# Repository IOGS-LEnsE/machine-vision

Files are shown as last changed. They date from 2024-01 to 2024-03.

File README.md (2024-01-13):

# Machine Vision Platform
Documentation of the pedagogic platform about Machine Vision used during labwors @ LEnsE / IOGS / France

Watch the complete documentation [here !!!](https://iogs-lense.github.io/machine-vision/)

## About Institut d'Optique and LEnsE
The **LEnsE**, ***Laboratoire d'Enseignement Expérimental***, [Website](http://lense.institutoptique.fr/)

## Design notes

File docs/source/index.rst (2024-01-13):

.. Machine-Vision platform documentation master file, created by
   sphinx-quickstart on Sat Jan 13.
   You can adapt this file completely to your liking, but it should at least contain the root `toctree` directive.

Documentation of Machine Vision platform
========================================

.. caution::
   This documentation website is still in development

**Machine Vision** GitHub repository contains documentations of the pedagogic technical platform developed for Machine Vision labworks and projects of students.

The GitHub repository of this project : `Machine Vision <https://github.com/IOGS-LEnsE/machine-vision>`_

|

.. toctree::
   :maxdepth: 1
   :caption: Machine Vision
   
	Machine Vision platform<contents/machine_vision>

.. toctree::
   :maxdepth: 1
   :caption: Materials

	Overview<contents/material_overview>
	Electronic board<contents/material_board>
	Testing procedure<contents/material_testing>

.. toctree::
   :maxdepth: 1
   :caption: How To

.. toctree::
   :maxdepth: 1
   :caption: Contributors
   
	Main contributors<contents/main_contributors>
	Students contributions<contents/other_contributors>

About the LEnsE
---------------

The **Experimental Teaching Laboratory** (*LEnsE*, for *Laboratoire d’ENSeignement Expérimental*) is a major structure of the *Institut d'Optique* engineering school. It offers remarkably strong training that contributes 25% of the total curriculum. It is an impressive structure where students have access to a large diversity of material and human resources to be able to gain the skills to become excellent experimenters recognized in their field.

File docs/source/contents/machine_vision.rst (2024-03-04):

Machine Vision Platform
=======================

Machine vision
--------------

**Machine vision** encompasses all industrial and non-industrial applications in which a **combination of hardware and software** provide operational guidance to devices in the execution of their functions based on the capture and processing of images.

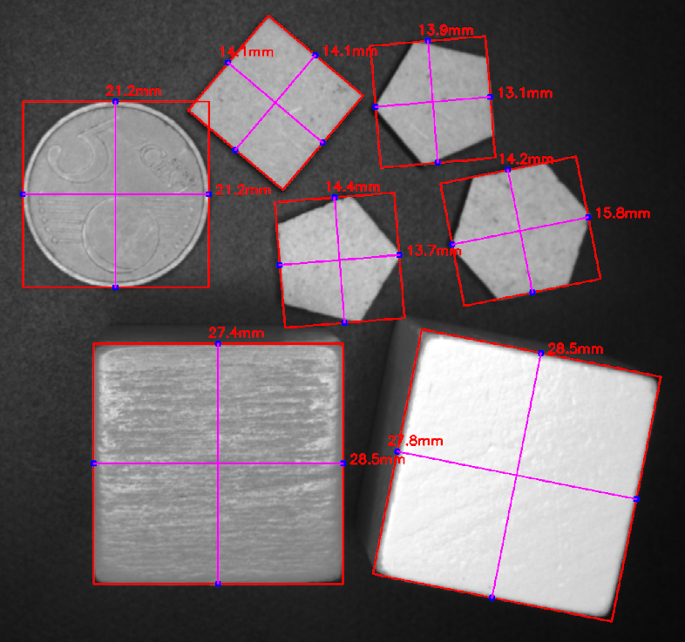
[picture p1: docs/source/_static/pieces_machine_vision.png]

  
  2022 LEnsE.

For example, machine vision is used to inspect parts in a production chain without stopping the manufacturing flow. If defaults are detected on a part (wrong color, bad shape...), a sorting system can eject bad elements.

|

In manufacturing settings, machine vision systems required the following items:

#. **Lighting** to illuminate the scene to make the object features visible.
#. **Lens** to captures the image and delivers it to a sensor.
#. **Image sensor** to collect a digital image of the object.
#. **Computer** (or digital signal processor) to process the images and extract the required information.

|

You can find more information about machine vision, for example, on the Cognex website : https://www.cognex.com/en-au/what-is/machine-vision

Pedagogical platform
--------------------

The platform was developped in order to sort pieces 

It is based on :

#. *EffiLux* **Effi-Ring** industrial lights 
#. A `Dobot Magician **Conveyor** <https://www.dobot.nu/en/product/dobot-conveyor-belt-kit/>`_ (step-motor and conveyor belt)
#. A *Basler* camera sensor

Pedagogical objectives
----------------------

Niveau 1 : pilotage du convoyeur
Niveau 2 : détection de forme et de couleur par caméra

Dans le milieu industriel, le convoyage de pièces, la détection de certains défauts ou le tri par types d’objets sont très couramment utilisés. L’objectif de ce projet est de mettre en place un système de tri de pièces à l’aide d’un convoyeur et d’un système de traitement d’images.

La mise en mouvement du convoyeur se fait par l’intermédiaire d’un moteur pas à pas. Le tri des pièces (par couleur ou forme) utilise une caméra associée à une Raspberry Pi permettant de faire le traitement des images et de transmettre le résultat à un système de tri.

Main steps
----------

Interface de base
~~~~~~~~~~~~~~~~~

Des bibliothèques de base en Python sont disponibles pour le développement autour des caméras Basler. Ces exemples nécessitent opencv et les API pypylon (Basler). Ces exemples peuvent être inclus dans des interfaces graphiques en PyQt6.

`Exemples pour cameras IDS et Basler <https://github.com/IOGS-Digital-Methods/SupOpNumTools/tree/main/src/SupOpNumTools/camera>`_

Des exemples (très complets) sont disponibles dans les projets suivants :  `IHM PyQt6 pour cameras IDS et Basler <https://github.com/IOGS-LEnsE/labwork-GUI>`_

Une première version d’une interface de commande (obsolète) des caméras IDS USB2 est disponible.  `IHM PyQt5 pour camera IDS - obsolete <https://github.com/IOGS-LEnsE-embedded/Python_SupOpLibraries/tree/main/CameraControl/IDS/LEnsE_version1>`_

*Cette application nécessite PyQt5, OpenCV, l’API PyUeye et les drivers des caméras.*

Partie matérielle
~~~~~~~~~~~~~~~~~

* Comprendre le fonctionnement d'un moteur pas à pas (indépendamment de ceux de la table) - `Vidéo <https://www.youtube.com/watch?v=eyqwLiowZiU>`_
* Etudier les signaux à appliquer sur le moteur pas à pas pour l'entrainer en rotation
* Etudier le driver `**TMCSILENTSTEPSTICK** <https://fr.farnell.com/trinamic/tmc-silentstepstick/carte-driver-moteur-pas-a-pas/dp/2822153>`_ (basé  sur un composant de type **TMC2100**) et l'associer au moteur pas à pas
* Voir aussi les tutoriels associés aux cartes Nucléo parlant des étages de puissance
	* Régler l’intensité lumineuse d’une LED – partie puissance
	* Faire varier la vitesse d’un moteur à courant continu – partie pont en H
* Réaliser un programme de pilotage simple pour entrainer en rotation le moteur

Partie logicielle / traitement d’image
~~~~~~~~~~~~~~~~~~~~~~~~~~~~~~~~~~~~~~

* Prendre en main PyQt6 sous Python 3
* Tester les fonctionnalités de base de Open CV sous Python

Autres étapes

* Mettre en place une communication RS232 entre la Raspberry Pi (via un programme en Python) et une carte Nucléo
* Décider des données à transmettre de l’un à l’autre et d’un protocole à mettre en oeuvre
* Tester le code de la carte Nucléo à l’aide de commande directement saisie dans un terminal
* Voir aussi les tutoriels associés aux cartes Nucléo parlant des communications inter-systèmes
	* Echanger des données entre deux systèmes communicants (et les tutoriels précédents sur la communication RS232)

Une série de tutoriels sont en cours de rédaction à ce sujet :  `Tutoriel Python / PySerial et PyQt5/6 pour échange entre un PC et une Nucléo <http://lense.institutoptique.fr/mine/python-interfacage-et-affichage/>`_

Ils sont basés sur les exemples suivants :  `IHM PyQt5 pour échange entre un PC et une Nucléo <https://github.com/IOGS-LEnsE-embedded/Python_SupOpLibraries/tree/main/SerialComm>`_

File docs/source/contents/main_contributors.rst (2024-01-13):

Labworks Platforms Development / Main Contributors
==================================================

Initial Idea
------------

The original idea of this platform borned with a regular request for training in Machine Vision to the *Continuing Education* service of the **Institut d'Optique**.

This platform was also designed as a main industrial application of image processing for our future engineer in photonics.

Initial Design
--------------

The initial design of the platform was performed by **Thierry AVIGNON**, technical engineer at LEnsE, and **Julien VILLEMEJANE**, professor at LEnsE.

The main objective was to integrate the **basic components of an industrial machine vision platform** (image sensor, lighting system, image processing) and a sorting application level.

Learning outcomes targeted by this platform are for our future engineer :

* list the main components of a machine vision system
* choose and interface image sensor (and optical system) to obtain relevant images
* experiment the impact of the lighting system on the quality of the image
* develop a sorting application of pieces, depending on their shape or/and their color

Main development
----------------

A first platform was developped at LEnsE as part of a three weeks students project in 2022 by Victoire de SALEON, Flora SILBERZAN, Oscar BOUCHER, Martin COLLIGNON, Samuel GERENTE and Hugo LASSIETTE (promo 2024), framed by **Thierry AVIGNON** and **Julien VILLEMEJANE**. A poster of their work is available by following `this link <http://lense.institutoptique.fr/ressources/MINE/Realisations/PIMS/2022_VisionIndustrielle/2022_PIMS_VisionIndustrielle_Poster.pdf>`_.

Continuous Upgrades
-------------------

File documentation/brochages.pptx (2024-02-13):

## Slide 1

Computer Vision / L476 board

Control of computer vision bench / Dobot conveyor

Functions

- Step Motor Control (x2)
  - Step Motor Driver – TMC2100
- RF data transmission
  - RN41/42 – Evaluation Board XV
- Position sensor SEN0239 (x3)
- Light control (x3 – R / G / B)

PROJECT VERSION

Based on Nucleo L476RG board

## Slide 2

Computer Vision / L476 board

Control of computer vision bench / Dobot conveyor

TX

PC_10

PC_12

Morpho Gauche / Nucléo

PC_11

PD_2

E5V

GPIO2_STATUS

RX

POUSS. 3

PC_9

PB_8

PB_9

Morpho Droit / Nucléo

PC_8

PC_6

PC_5

POUSS. 2

POUSS. 1

PA_13

GND

nRF24 / SCK

AVDD

GND

PA_5 / SCK

U5V

PA_12

PA_14

PA_15

5V

3.3V

nRF24 / MOSI

nRF24 / MISO

PA_6 / MISO

PA_7 / MOSI

D10 / CS

PA_11

PB_12

PB_11

LED 1

LED 2

RESET_N

GND

PB_7

PC_13

Vin

PA_0

GND

GND

nRF24 / CSN

nRF24 / CE

nRF24 / IRQ

PC_7

PA_9

PA_8

GND

PB_1

PB_2

MOT1_CFG3

CAPT 1

CAPT 2

PC_14

PC_15

MOT2_EN

MOT2_DIR

MOT2_STEP

PB_10

PB_4

PB_5

PB_13

PB_15

PB_14

MOT1_CFG2

MOT1_CFG1

MOT1_EN

Not Used

Digital Output

Digital Input

Analog Input

CAPT 3

ECLAIR 3

PH_0

PH_1

PC_2

A2

PA_1

PB_0

V_OUT_REF

MOT1_STEP

MOT1_DIR

D1

PA_10

PB_3

PC_4

AGND

MOT1_STEP*

ECLAIR 2

ECLAIR 1

Analog Output

PC_3

PC_0

PC_1

D0

* Must be set as input

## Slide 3

TMC2100 – Step Motor Driver

Step Motor Driver / Motor 1 / TMC2100

MBED6 Library : https://github.com/IOGS-LEnsE-embedded/MBED6_SupOpLibraries/tree/main/TMC2100

Nucleo Board

Not Used

Digital Output

Digital Input

Analog Input

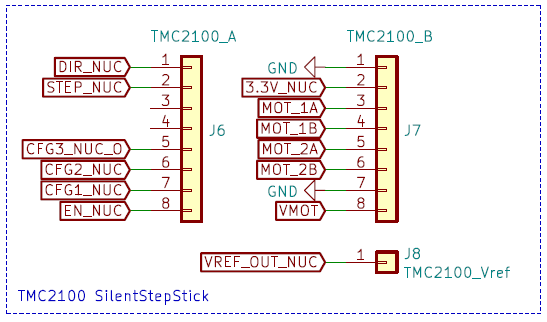
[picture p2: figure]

GND

TMC2100 / Motor1

PA_10

PB_3

MOT1_DIR

MOT1_STEP

3.3V

PB_1

MOT1_CFG3

PB_13

PB_15

PB_14

MOT1_CFG2

MOT1_CFG1

MOT1_EN

PC_4

PWM

MOT1_STEP

A2

V_OUT_REF

Analog Output

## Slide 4

nRF24 – RF transmission

nrF24L01 module for RF data transmission

MBED6 Library : https://github.com/IOGS-LEnsE-embedded/MBED6_SupOpLibraries/tree/main/nRF24

Nucleo Board

Not Used

Digital Output

Digital Input

Analog Input

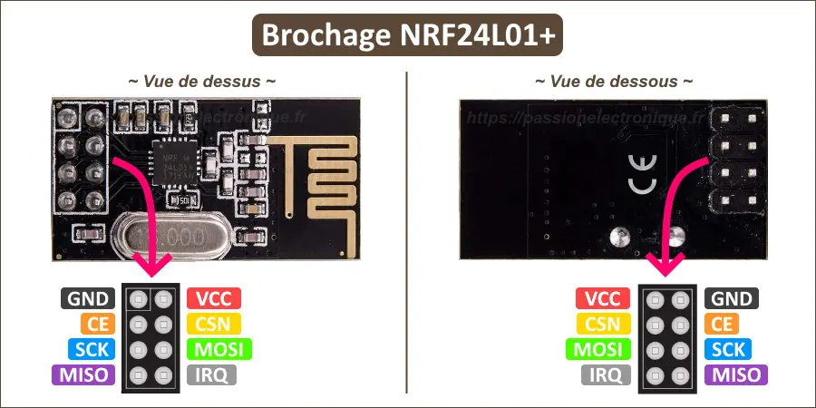
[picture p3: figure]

3.3V

GND

nRF24L01 / RF

PA_9

PA_8

PC_7

IRQ

CE

CSN

PA_6 / MISO

PA_7 / MOSI

PA_5/ SCK

SPI

MISO

MOSI

CLK

Analog Output

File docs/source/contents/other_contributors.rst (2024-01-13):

Light Source Radiant Intensity Measuring Platform
=================================================

.. caution::
   This documentation section is still in development

Machine Learning and first documentation
----------------------------------------

In 2023, during his first year of training, **Alexis CORBILLET** (2025 promotion) worked with five others classmates on the beta version of the machine vision bench. 

They worked on hardware part to develop a sorting system, but also on a software able to interact with users and process images from an IDS sensor to detect the color and the shape of the pieces to sort. Their system was based on Machine Learning algorithm.

The entire documentation of their application was written by Alexis using `Sphinx <https://www.sphinx-doc.org/en/master/>`_ : https://alex6crbt.github.io/Industrial_Vision/

The GitHub repository https://github.com/Alex6Crbt/Industrial_Vision was also developed by Alexis for his own training on GitHub processes. This repository and its documentation served as a basis for setting up this first LEnsE technical repository.

Alexis was helped by **Olivier LEVEQUE**, researcher at ONERA, the French Aerospace Lab.

Students Projects year by year
------------------------------

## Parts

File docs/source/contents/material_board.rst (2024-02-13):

Machine Vision Electronic Control board
=======================================

This platform is associated to an **electronic board** for controlling : the translation of the conveyor, the activation of each sorting system, the activation of the lighting system.

.. note::
	This board can be used to control 2 different step-motors.

Microcontroller
---------------

Pinouts
~~~~~~~

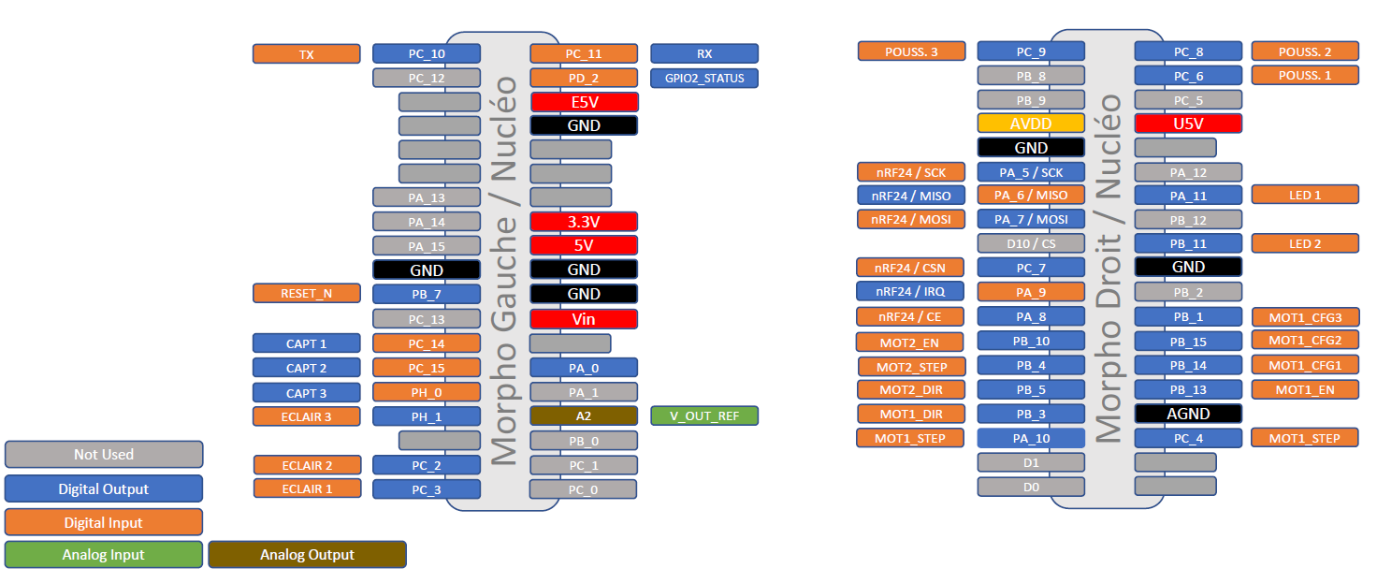
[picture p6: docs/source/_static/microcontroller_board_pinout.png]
Pinout of the microcontroller

   
   Pinouts of the board
   
Step-motor of the conveyor
--------------------------

The step-motor must be powered by a **4.6** to **4.8 V** continuous source, connected to the ... connector of the board.

Power stage and step motor driver
---------------------------------

Two step-motors can be controlled independently  by two **TMC2100** (`Kit TMC Silent Step Stick <https://fr.farnell.com/trinamic/tmc-silentstepstick/carte-driver-moteur-pas-a-pas/dp/2822153>`_) drivers.

The first driver (**Motor 1**) can be configured by CFG1, CFG2 and CFG3 pins (see `TMC2100 Documentation <https://www.utmel.com/productdetail/trinamicmotioncontrolgmbh-tmc2100tat-5369295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>`_).
The second driver (**Motor 2**) is already set up as CFG3=open (*External reference voltage on pin AIN*), CFG2/1=0b01 (*HalfSteps*).

.. list-table:: TMC2100 Pins / Motor 1
   :widths: 34 33 33
   :header-rows: 1

   * - TMC2100
     - Elec Board
     - Nucleo Board
   * - EN (In)
     - MOT1_EN (Out)
     - PB_13
   * - DIR (In)
     - MOT1_DIR (Out)
     - PB_3
   * - STEP (In)
     - MOT1_STEP (Out)
     - PA_10
   * - CFG1 (In)
     - MOT1_CFG1 (Out)
     - PB_14
   * - CFG2 (In)
     - MOT1_CFG2 (Out)
     - PB_15
   * - CFG3 (In)
     - MOT1_CFG3 (Out)
     - PB_1
   * - VREF_AIN (Analog In)
     - V_OUT_REG (Analog Out)
     - PA_4 / A2

To configure CFG3 as open pin, the J2 jumper must be removed (*External reference voltage on pin AIN*). To connect the CFG3 input pin of the TMC2100 driver to the Nucleo Board (MOT1_CFG3 pin), the J2 jumper must be in place.

.. list-table:: TMC2100 Pins / Motor 2
   :widths: 34 33 33
   :header-rows: 1

   * - TMC2100
     - Elec Board
     - Nucleo Board
   * - EN (In)
     - MOT2_EN (Out)
     - PB_10
   * - DIR (In)
     - MOT2_DIR (Out)
     - PB_5
   * - STEP (In)
     - MOT2_STEP (Out)
     - PB_4
   * - VREF_AIN (Analog In)
     - V_OUT_REG (Analog Out)
     - PA_4 / A2

An external power supply must be connected to the J5 connector (VMOT). This nominal supply for the xxx step-motor is 4V, for a maximal current of 1A per phase.

More details on the `TMC2100 Documentation <https://www.utmel.com/productdetail/trinamicmotioncontrolgmbh-tmc2100tat-5369295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>`_.

A library for TMC2100 and an example of use is available : `TMC2100 Library and example <https://github.com/IOGS-LEnsE/machine-vision/blob/main/progs/step_motor_tmc2100/step_motor_tmc2100.zip>`_.

Presence sensors
----------------

Three digital inputs are dedicated to **SEN0239** infrared presence detectors, including supply of the sensors.

.. list-table:: Presence Sensors Pins
   :widths: 34 33 33
   :header-rows: 1

   * - Sensor
     - Elec Board
     - Nucleo Board
   * - Sensor 1
     - CAPT1 (In)
     - PC_14
   * - Sensor 2
     - CAPT2 (In)
     - PC_15
   * - Sensor 3
     - CAPT3 (In)
     - PH_0

Communication
-------------

A **RN41/42 XV** module or a **nrF24L01** module could be implemented for radio-frequency communication. 

BlueTooth communication via RN41/42 module
~~~~~~~~~~~~~~~~~~~~~~~~~~~~~~~~~~~~~~~~~~

RF communication via nRF24L01 module
~~~~~~~~~~~~~~~~~~~~~~~~~~~~~~~~~~~~

.. list-table:: nRF24L01 Pins
   :widths: 34 33 33
   :header-rows: 1

   * - nRF24L01
     - Elec Board
     - Nucleo Board
   * - SCK / In
     - nRF24 / SCK (Out)
     - PA_5 / D13 *
   * - MISO / Out
     - nRF24 / MISO (In)
     - PA_6 / D12
   * - MOSI / In
     - nRF24 / MOSI (Out)
     - PA_7 / D11
   * - CSN / In
     - nrF24 / CSN (Out)
     - PC_7
   * - IRQ / Out
     - nrF24 / IRQ (In)
     - PA_9
   * - CE / In
     - nrF24 / CE (Out)
     - PA_8

* LED1 (LD2 on board led) could not be used if nrF24 is connected

Lighting system
---------------

The lighting system is an EFFI-Ring from the Effilux company, type RGB (ref ??). Red, Blue and Green lights can be controlled independently.

IMAGE OF THE LIGHT

A M12-5pins connector is used to control and power the ring. The power supply is 24V. The pins controlling the 3 independent sources are connected to a MOSFET transistor.

.. list-table:: Light Control Pins
   :widths: 34 33 33
   :header-rows: 1

   * - Light Source
     - Elec Board
     - Nucleo Board
   * - Red
     - ECLAIR 1
     - PC_3
   * - Green
     - ECLAIR 2
     - PC_2
   * - Blue
     - ECLAIR 3
     - PH_1

Lights are activated on a **low-level state** of the previous outputs (output = 0).

An external power supply must be connected to the J19 connector (V_ECLAIRAGE). The nominal supply for the EFFi-Ring source is 24V.

More details on the `EFFI-Ring Documentation <https://www.effilux.com/fr/produits/annulaire/effi-ring>`_.

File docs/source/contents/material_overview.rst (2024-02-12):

Overview of the platform
========================

The **LEnsE** team developped a platform to reproduce a part of an **industrial system of machine vision**.

Machine Vision platform is a combination of a **conveyor** driven in movement by a **step motor**, a sorting system, a **CMOS industrial sensor** and a **lighting system**.

PICTURE OF THE SYSTEM

Materials
---------

Conveyor and sorting system
~~~~~~~~~~~~~~~~~~~~~~~~~~~

This platform is mainly based on a **Dobot conveyor** that permits to transport small pieces 

Step Motor
""""""""""

A **step-motor** is used to move the conveyor. It is driven by a **TMC SILENTSTEPSTICK** from *Analog Devices*.

The step-motor must be powered up by a 4.6 to 4.8 V power supply.

Sensors
"""""""

Three **SEN0239** infrared presence detectors could be implemented on the board.

SCHEMA ?

A digital output is at a **high level** when an object is detected close to the sensor and at a low level when no object is detected. The sensibility (i.e. the detection distance) can be set up by modifying the value of a potentiometer using a screwdriver.

Sorter System
~~~~~~~~~~~~~

The conveyor is equiped with three home-made sorter systems, based on a servomotor.

IMAGE ?

CMOS Sensor
~~~~~~~~~~~

The CMOS Camera is a **Basler** *XXXX*. The **Pylon Camera Software Suite** is a software package comprised of an easy-to-use SDK, drivers, configuration tools and vTools that you can use to operate any Basler camera and utilize image processing using a Windows PC.

IMAGE OF THE SENSOR

You can also interface this camera with a Python program, using the `PyPylon library <https://github.com/basler/pypylon>`_.

An example based on the PyPylon library is given on this GitHub page : https://github.com/IOGS-Digital-Methods/SupOpNumTools/blob/main/src/SupOpNumTools/camera/cameraBasler.py

More details on the `Basler Documentation Website <https://www.baslerweb.fr/fr/20-cameras-matricielles>`_.

| 

Electronic control board
~~~~~~~~~~~~~~~~~~~~~~~~

This platform is associated to an **electronic board** for controlling : the translation of the conveyor, the activation of each sorting system, the activation of the lighting system.

.. note::
	This board can be used to control 2 different step-motors.

IMAGE OF THE BOARD

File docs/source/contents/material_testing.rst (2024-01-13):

Machine Vision Testing procedures
=================================

Power supplies
--------------

Lighting system
---------------

Conveyor system
---------------

Image acquisition
-----------------

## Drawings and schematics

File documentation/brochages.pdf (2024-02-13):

# Computer Vision / L476 board

# Control of computer vision bench / Dobot conveyor

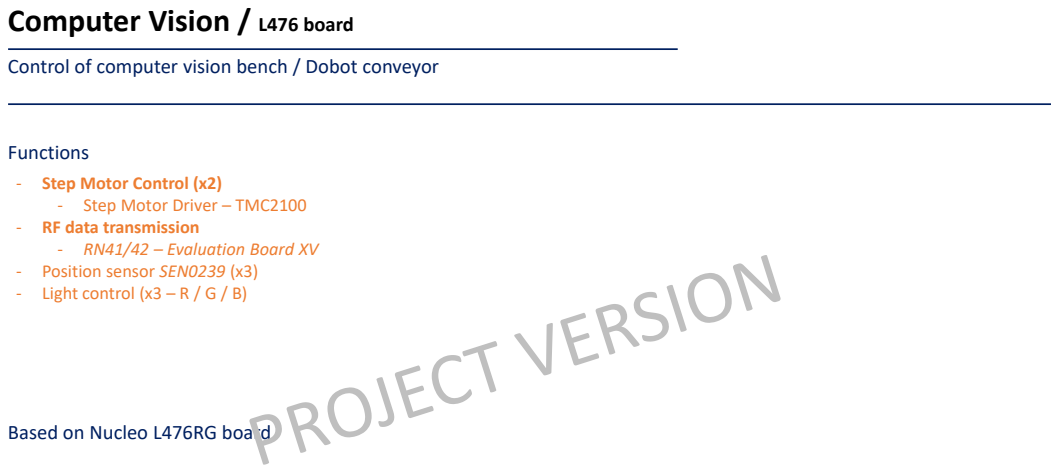
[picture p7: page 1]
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

Based on Nucleo L476RG board

# Computer Vision / L476 board

# Control of computer vision bench / Dobot conveyor

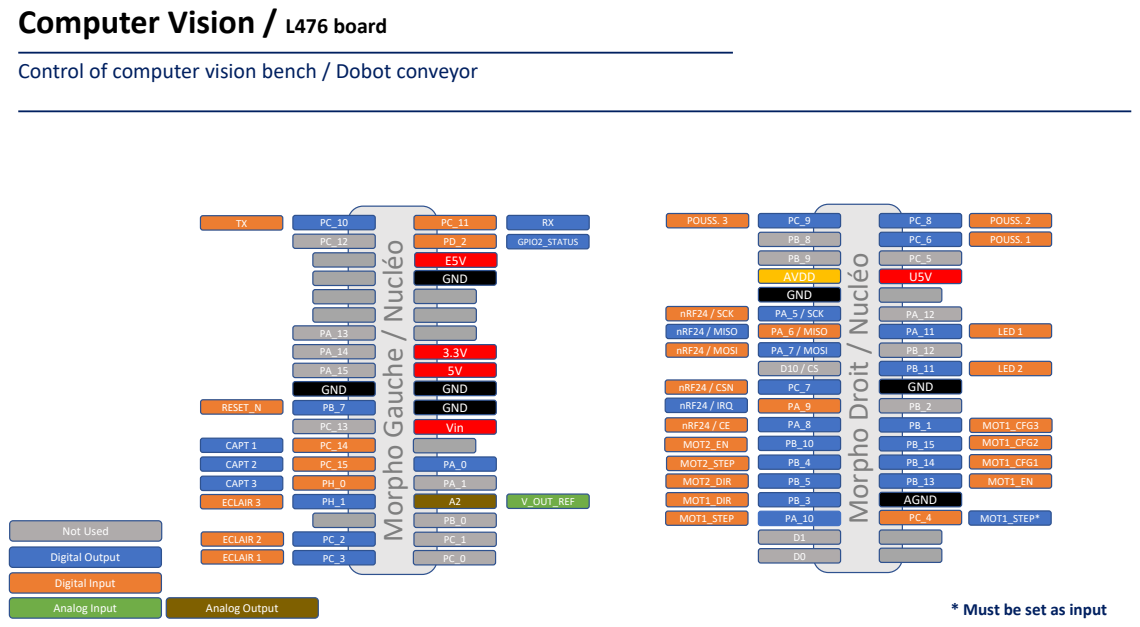
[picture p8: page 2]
Digital Output; Digital Input; Analog Input; PA_6 / MISO; PA_7 / MOSI; PA_5 / SCK; GND; AGND; AVDD; PD_2 E5V GND; GND Vin; RESET_N; GPIO2_STATUS; nRF24 / SCK; nRF24 / MISO; nRF24 / MOSI; nRF24 / IRQ; nRF24 / CSN; nRF24 / CE; Not Used; CAPT 1; CAPT 2; CAPT 3; ECLAIR 3; ECLAIR 2; ECLAIR 1; Analog Output; V_OUT_REF; POUSS. 3; POUSS. 2; POUSS. 1; LED 1; LED 2; MOT1_STEP; MOT1_DIR; MOT1_EN; MOT1_CFG1; MOT1_CFG2; MOT1_CFG3; MOT2_DIR; MOT2_STEP; MOT2_EN; MOT1_STEP*

Morpho Gauche / Nucléo

Morpho Droit / Nucléo

* Must be set as input

# TMC2100 – Step Motor Driver

# Step Motor Driver / Motor 1 / TMC2100 TMC2100 / Motor1

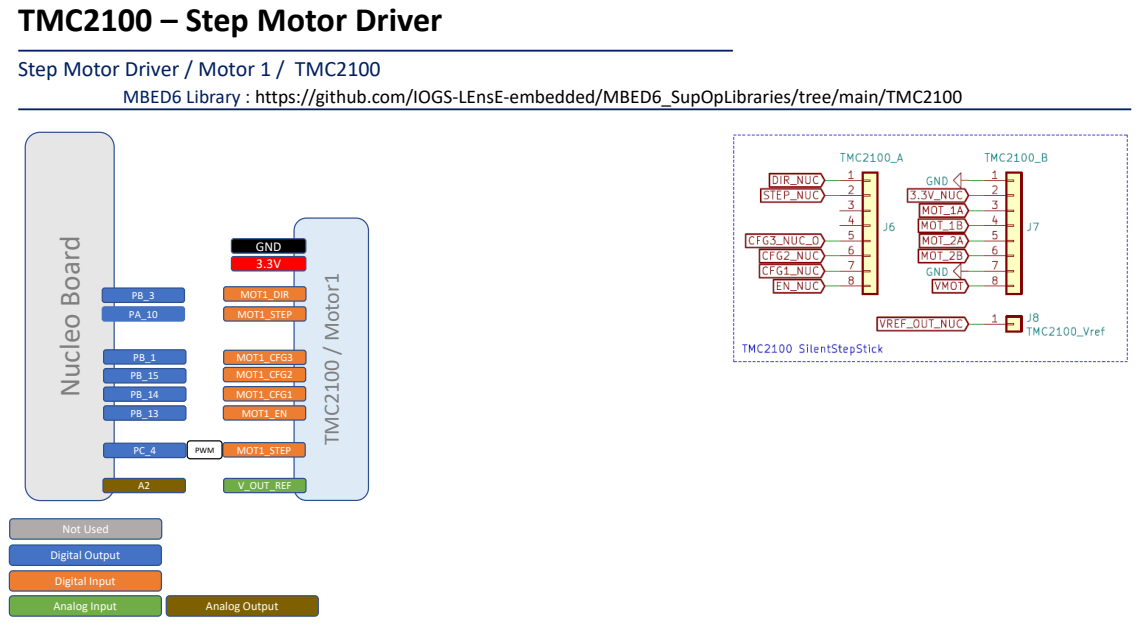
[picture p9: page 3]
Nucleo Board; GND 3.3V; MOT1_STEP; MOT1_DIR; MOT1_EN; MOT1_CFG1; MOT1_CFG2; MOT1_CFG3; PWM; V_OUT_REF; Digital Output; Digital Input; Not Used

MBED6 Library : https://github.com/IOGS-LEnsE-embedded/MBED6_SupOpLibraries/tree/main/TMC2100

# nRF24 – RF transmission

# nrF24L01 module for RF data transmission

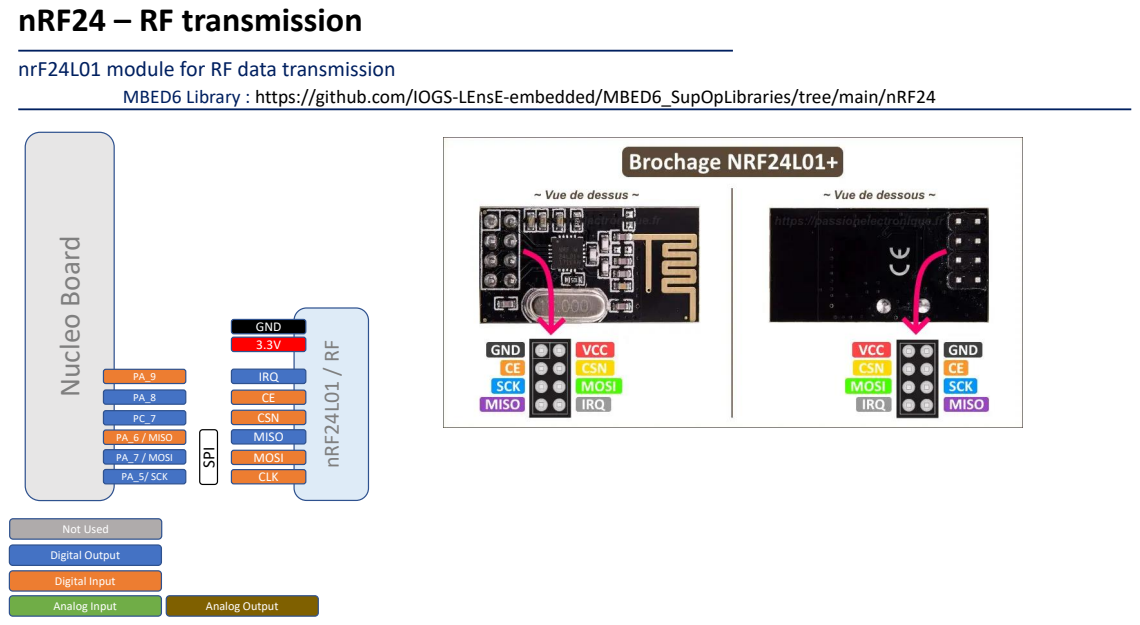
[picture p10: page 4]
Nucleo Board; PA_5/ SCK; nRF24L01 / RF; CLK; PA_7 / MOSI; MOSI; PA_6 / MISO; MISO SPI; CSN; IRQ; GND 3.3V; Digital Output; Digital Input; Not Used

MBED6 Library : https://github.com/IOGS-LEnsE-embedded/MBED6_SupOpLibraries/tree/main/nRF24

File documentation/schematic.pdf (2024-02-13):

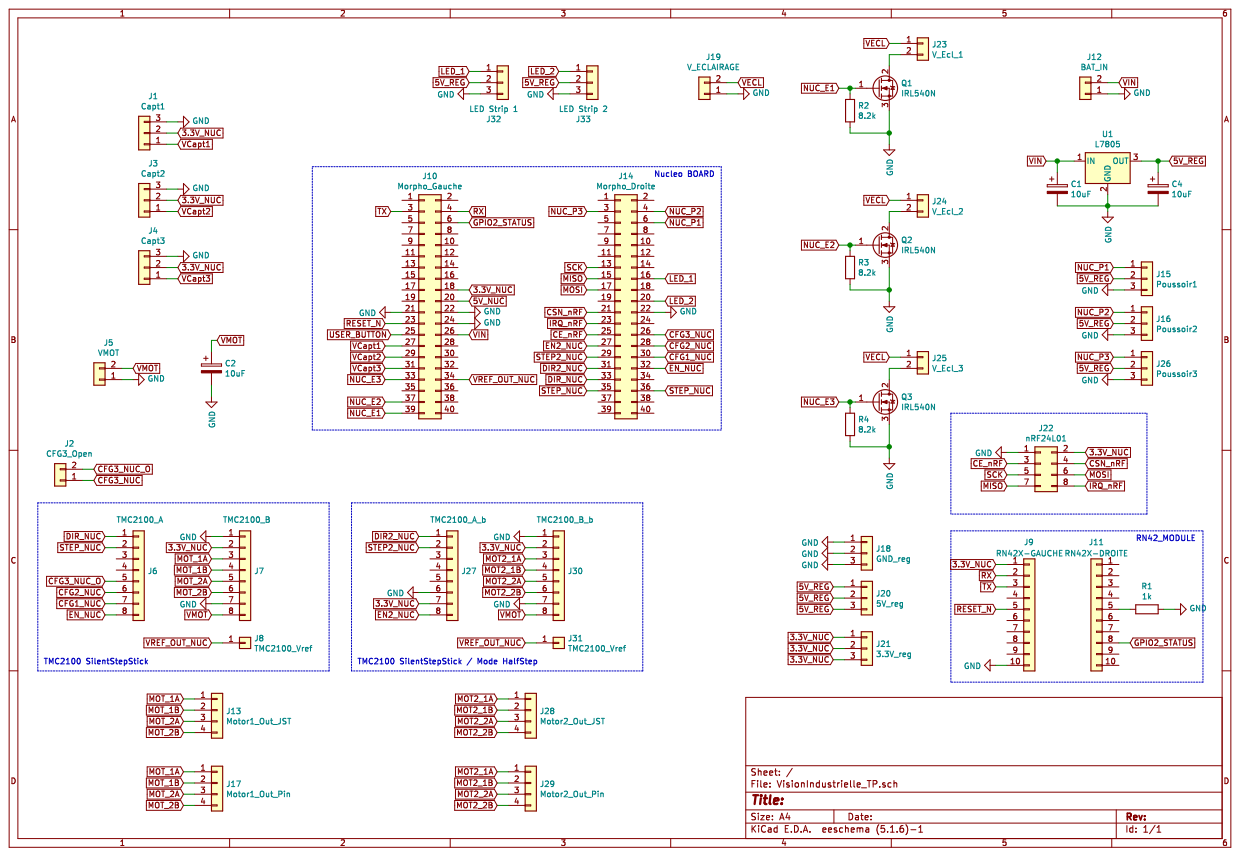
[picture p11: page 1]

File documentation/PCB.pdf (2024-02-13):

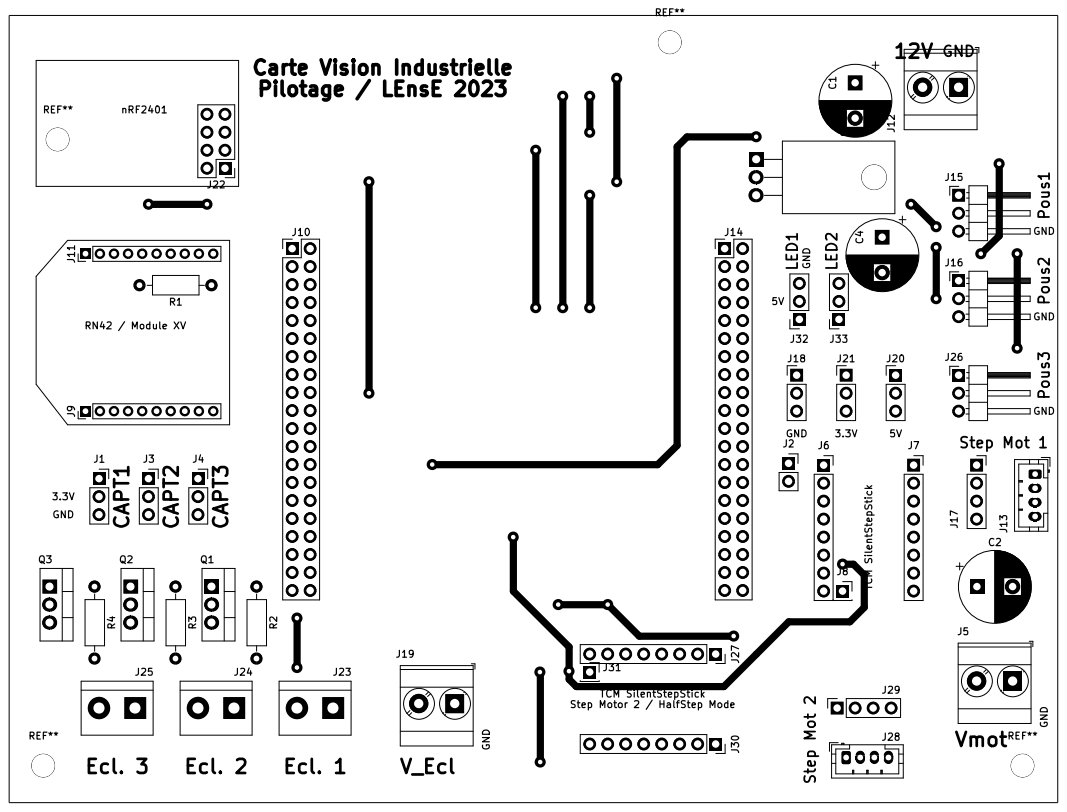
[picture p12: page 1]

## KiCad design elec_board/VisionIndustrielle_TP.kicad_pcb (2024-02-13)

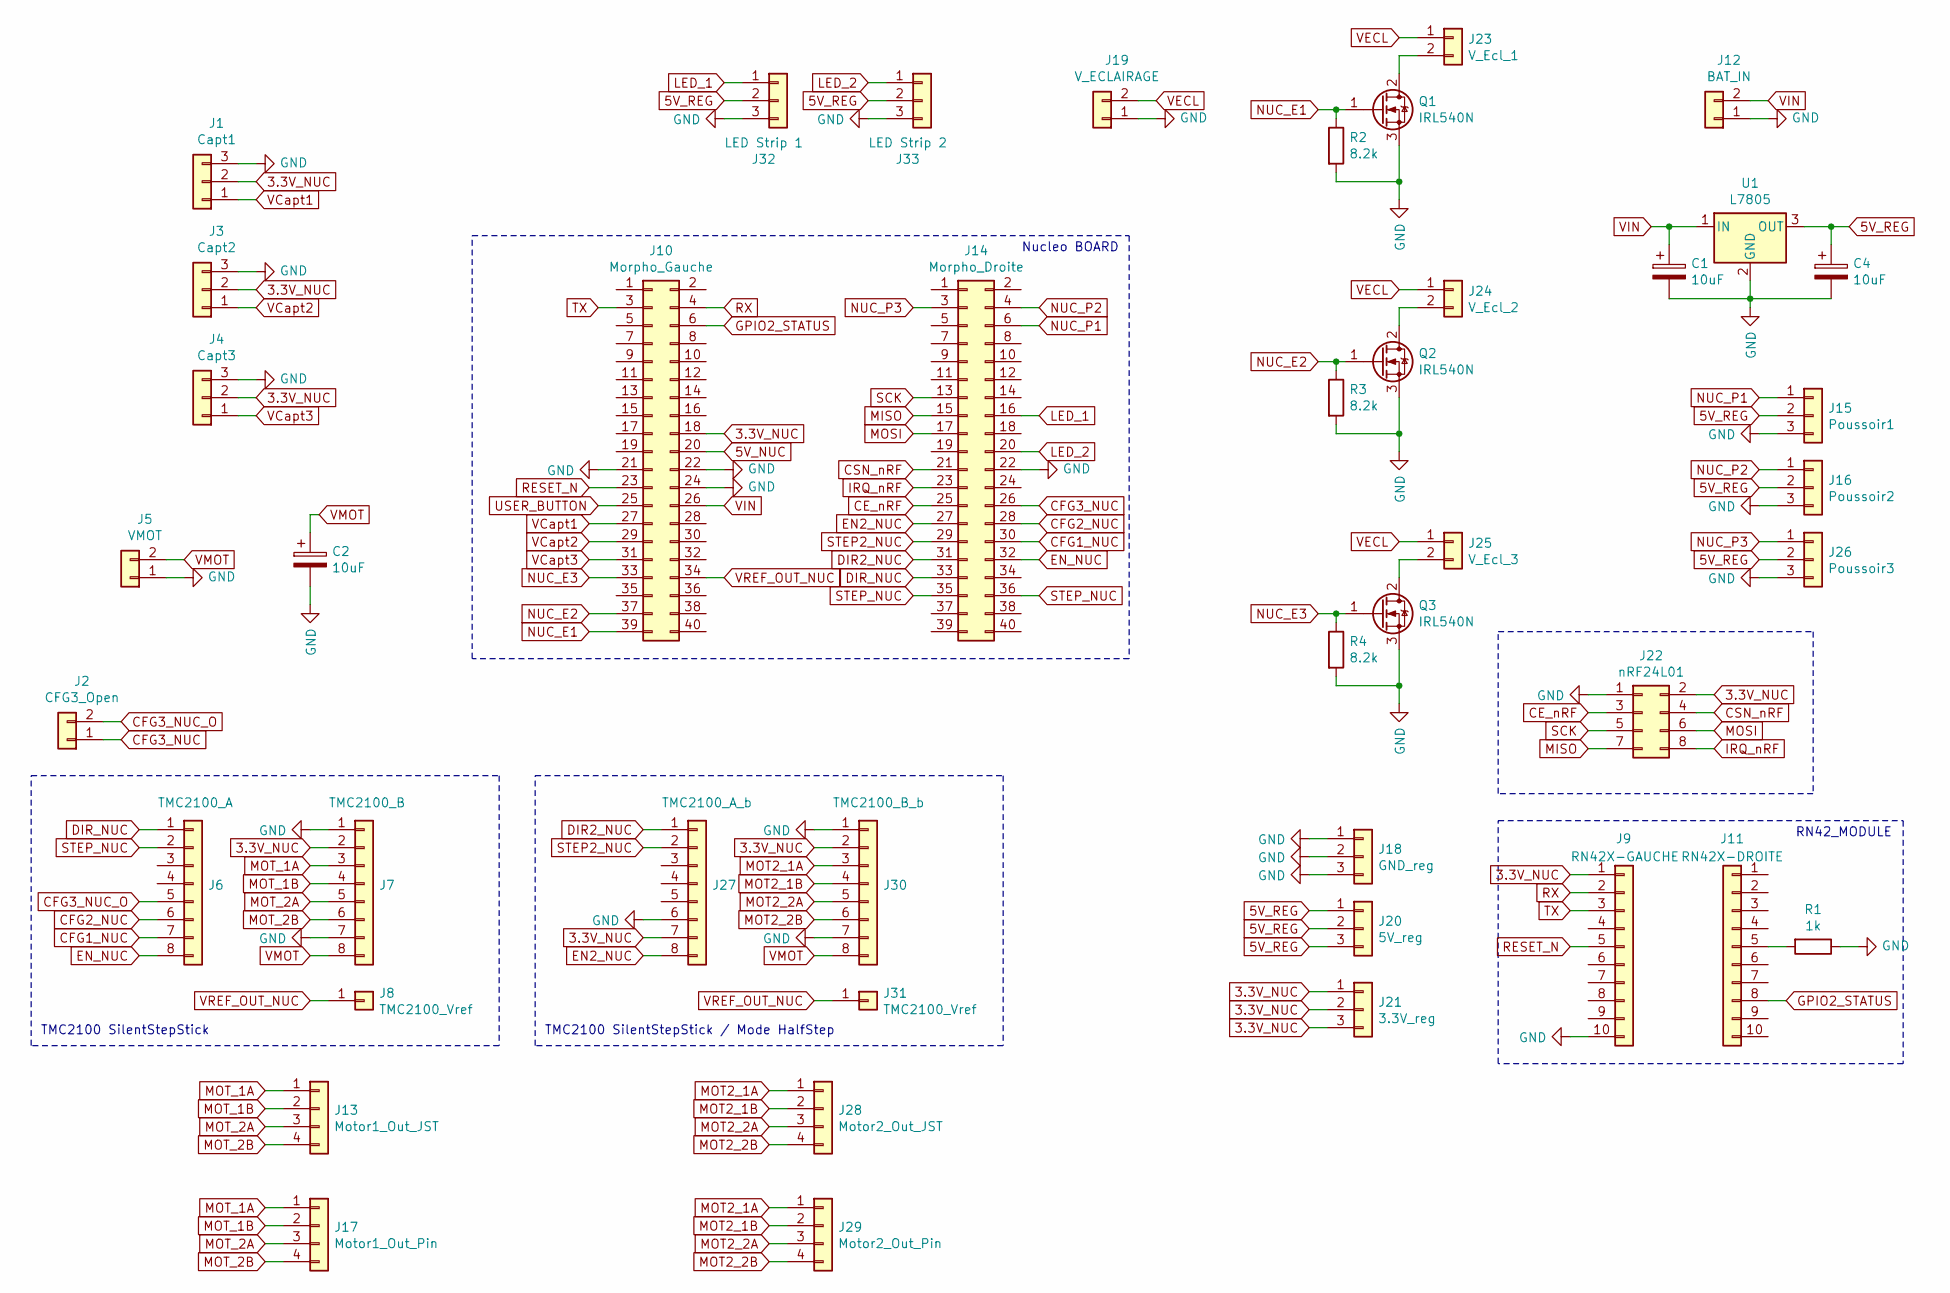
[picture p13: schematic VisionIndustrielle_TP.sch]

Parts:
C1, C2, C4: 10uF; CP_Radial_D10.0mm_P5.00mm
J1: Capt1; PinSocket_1x03_P2.54mm_Vertical
J2: CFG3_Open; PinSocket_1x02_P2.54mm_Vertical
J3: Capt2; PinSocket_1x03_P2.54mm_Vertical
J4: Capt3; PinSocket_1x03_P2.54mm_Vertical
J5: VMOT; TerminalBlock_Phoenix_MKDS-3-2-5.08_1x02_P5.08mm_Horizontal
J6: TMC2100_A; PinSocket_1x08_P2.54mm_Vertical
J7: TMC2100_B; PinSocket_1x08_P2.54mm_Vertical
J8, J31: TMC2100_Vref; PinSocket_1x01_P2.54mm_Vertical
J9: RN42X-GAUCHE; PinHeader_1x10_P2.00mm_Vertical
J10: Morpho_Gauche; PinHeader_2x20_P2.54mm_Vertical
J11: RN42X-DROITE; PinHeader_1x10_P2.00mm_Vertical
J12: BAT_IN; TerminalBlock_Phoenix_MKDS-3-2-5.08_1x02_P5.08mm_Horizontal
J13: Motor1_Out_JST; JST_PH_B4B-PH-K_1x04_P2.00mm_Vertical
J14: Morpho_Droite; PinHeader_2x20_P2.54mm_Vertical
J15: Poussoir1; PinHeader_1x03_P2.54mm_Horizontal
J16: Poussoir2; PinHeader_1x03_P2.54mm_Horizontal
J17: Motor1_Out_Pin; PinSocket_1x04_P2.54mm_Vertical
J18: GND_reg; PinHeader_1x03_P2.54mm_Vertical
J19: V_ECLAIRAGE; TerminalBlock_Phoenix_MKDS-3-2-5.08_1x02_P5.08mm_Horizontal
J20: 5V_reg; PinHeader_1x03_P2.54mm_Vertical
J21: 3.3V_reg; PinHeader_1x03_P2.54mm_Vertical
J22: nRF24L01; PinHeader_2x04_P2.54mm_Vertical
J23: V_Ecl_1; TerminalBlock_bornier-2_P5.08mm
J24: V_Ecl_2; TerminalBlock_bornier-2_P5.08mm
J25: V_Ecl_3; TerminalBlock_bornier-2_P5.08mm
J26: Poussoir3; PinHeader_1x03_P2.54mm_Horizontal
J27: TMC2100_A_b; PinSocket_1x08_P2.54mm_Vertical
J28: Motor2_Out_JST; JST_PH_B4B-PH-K_1x04_P2.00mm_Vertical
J29: Motor2_Out_Pin; PinSocket_1x04_P2.54mm_Vertical
J30: TMC2100_B_b; PinSocket_1x08_P2.54mm_Vertical
J32: LED Strip 1; PinSocket_1x03_P2.54mm_Vertical
J33: LED Strip 2; PinSocket_1x03_P2.54mm_Vertical
Q1, Q2, Q3: IRL540N; TO-220-3_Vertical
R1: 1k; R_Axial_DIN0207_L6.3mm_D2.5mm_P10.16mm_Horizontal
R2, R3, R4: 8.2k; R_Axial_DIN0207_L6.3mm_D2.5mm_P10.16mm_Horizontal
U1: L7805; TO-220-3_Horizontal_TabDown

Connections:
3.3V_NUC: J1.2, J3.2, J4.2, J7.2, J9.1, J10.18, J21.1, J21.2, J21.3, J22.2, J27.7, J30.2
5V_NUC: J10.20
5V_REG: C4.1, J15.2, J16.2, J20.1, J20.2, J20.3, J26.2, J32.2, J33.2, U1.3 (OUT)
CE_nRF: J14.25, J22.3
CFG1_NUC: J6.7, J14.30
CFG2_NUC: J6.6, J14.28
CFG3_NUC: J2.1, J14.26
CFG3_NUC_O: J2.2, J6.5
CSN_nRF: J14.21, J22.4
DIR2_NUC: J14.31, J27.1
DIR_NUC: J6.1, J14.33
EN2_NUC: J14.27, J27.8
EN_NUC: J6.8, J14.32
GND: C1.2, C2.2, C4.2, J1.3, J3.3, J4.3, J5.1, J7.1, J7.7, J9.10, J10.21, J10.22, J10.24, J12.1, J14.22, J15.3, J16.3, J18.1, J18.2, J18.3, J19.1, J22.1, J26.3, J27.6, J30.1, J30.7, J32.3, J33.3, Q1.3 (S), Q2.3 (S), Q3.3 (S), R1.1, R2.2, R3.2, R4.2, U1.2 (GND)
GPIO2_STATUS: J10.6, J11.8
IRQ_nRF: J14.23, J22.8
LED_1: J14.16, J32.1
LED_2: J14.20, J33.1
MISO: J14.15, J22.7
MOSI: J14.17, J22.6
MOT2_1A: J28.1, J29.1, J30.3
MOT2_1B: J28.2, J29.2, J30.4
MOT2_2A: J28.3, J29.3, J30.5
MOT2_2B: J28.4, J29.4, J30.6
MOT_1A: J7.3, J13.1, J17.1
MOT_1B: J7.4, J13.2, J17.2
MOT_2A: J7.5, J13.3, J17.3
MOT_2B: J7.6, J13.4, J17.4
NUC_E1: J10.39, Q1.1 (G), R2.1
NUC_E2: J10.37, Q2.1 (G), R3.1
NUC_E3: J10.33, Q3.1 (G), R4.1
NUC_P1: J14.6, J15.1
NUC_P2: J14.4, J16.1
NUC_P3: J14.3, J26.1
unnamed: J11.5, R1.2
unnamed: J23.2, Q1.2 (D)
unnamed: J24.2, Q2.2 (D)
unnamed: J25.2, Q3.2 (D)
RESET_N: J9.5, J10.23
RX: J9.2, J10.4
SCK: J14.13, J22.5
STEP2_NUC: J14.29, J27.2
STEP_NUC: J6.2, J14.35, J14.36
TX: J9.3, J10.3
USER_BUTTON: J10.25
VCapt1: J1.1, J10.27
VCapt2: J3.1, J10.29
VCapt3: J4.1, J10.31
VECL: J19.2, J23.1, J24.1, J25.1
VIN: C1.1, J10.26, J12.2, U1.1 (IN)
VMOT: C2.1, J5.2, J7.8, J30.8
VREF_OUT_NUC: J8.1, J10.34, J31.1

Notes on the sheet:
RN42_MODULE
Nucleo BOARD
TMC2100 SilentStepStick
TMC2100 SilentStepStick / Mode HalfStep

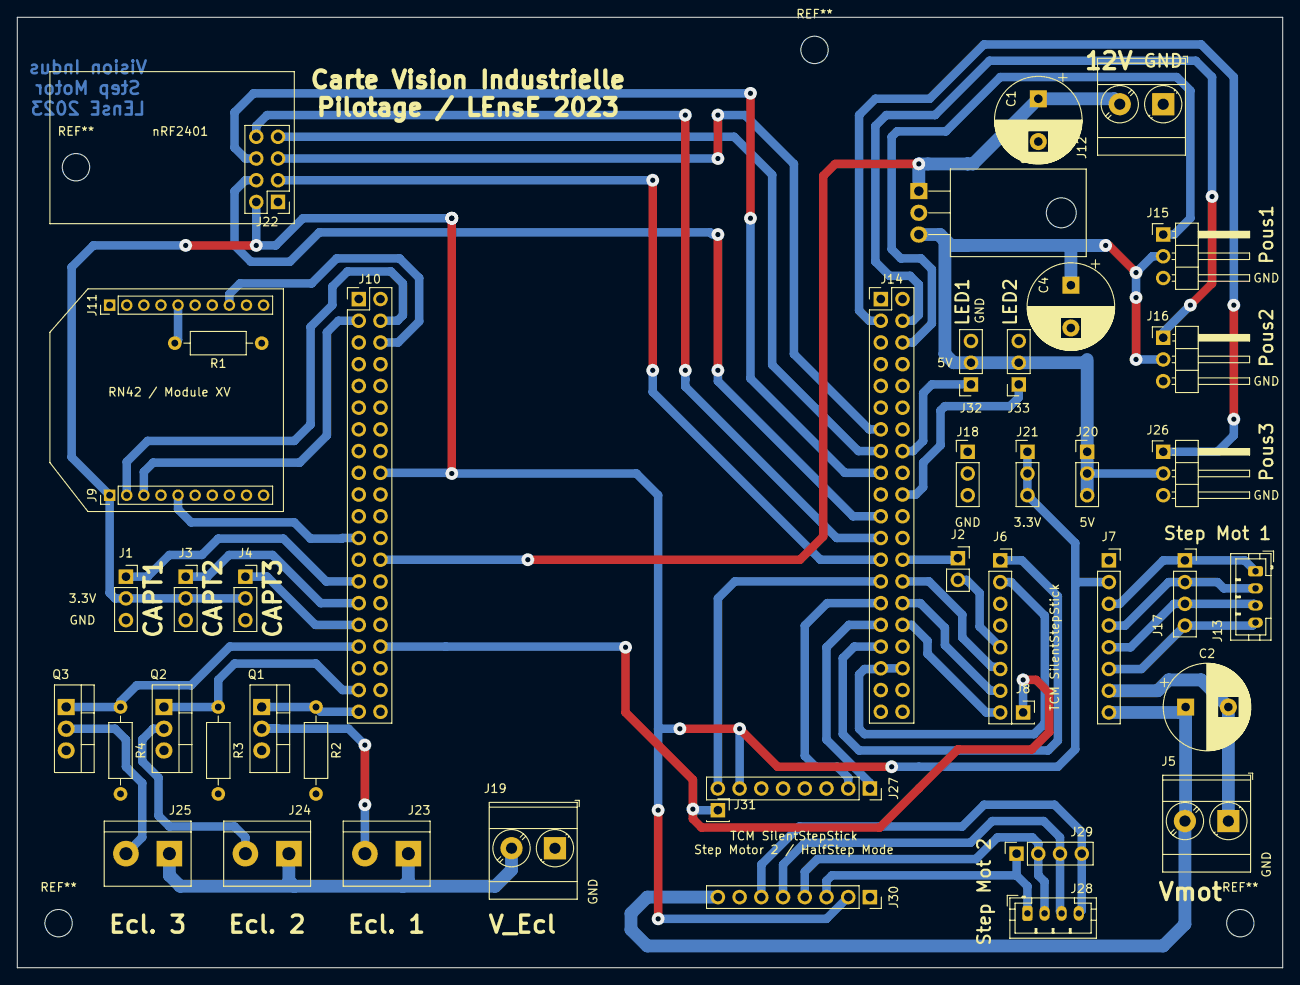
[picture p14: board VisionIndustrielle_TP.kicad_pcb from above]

Board: 2 copper layers, 148.0 x 111.1 mm, 44 parts (0 on the bottom side), 50 nets.

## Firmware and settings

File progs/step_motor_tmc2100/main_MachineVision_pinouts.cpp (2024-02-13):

/**
 * FILENAME :        main.cpp          
 *
 * DESCRIPTION :
 *       Machine Vision Conveyor system based on Nucleo Board
 *
 * NOTES :
 *       Developped by Villou / LEnsE
 **
 * AUTHOR :    Julien VILLEMEJANE        START DATE :    15/jan/2024
 *
 *       LEnsE / Institut d'Optique Graduate School
 *          http://lense.institutoptique.fr/
 *          https://github.com/IOGS-LEnsE/machine-vision
 */

#include "mbed.h"
#include "MachineVision_pinouts.h"

#define     MAX_MODE    4


/// JoyCar inputs/outputs declaration - based on Joy-It Car platform
Ticker controlLoopTik;

InterruptIn     mode_change(BUTTON1);
uint8_t         mode_val = 0;


/* Methods */
/**
 * Interrupt routine attached to the sampling of the Contol Loop System
 *
 * @return Updates the system control loop outputs
 */
void ISR_controlLoopTik(void);

/**
 * Interrupt routine attached to the mode change button
 */
void ISR_change_mode(void);

/**
 * Test of the conveyor 
 */
void conveyor_test(void);

/* Main code */
int main()
{
    // Initialization 
    printf("Machine Vision / Platform Initialization\r\n");
    // 1/2 step
    M1_CFG1 = 0;
    M1_CFG2 = 0;

    // Light test
    Light_RED = 1;
    Light_GREEN = 1;
    Light_BLUE = 1;

    mode_change.fall(&ISR_change_mode);

    // Conveyor test
    conveyor_test();
    // Initialization of main ticker
    controlLoopTik.attach(&ISR_controlLoopTik, 100us);
    
    while (true){
    }
}


/* */
void ISR_controlLoopTik(void){


}

/* */
void ISR_change_mode(void){
    if(mode_val >= MAX_MODE-1){
        mode_val = 0;
    }
    else{
        mode_val++;
    }

    switch(mode_val){
        case 0:
            my_motor.goForward(250);
            printf("\tM-0-Forward\r\n");
            Light_RED = 0;
            Light_GREEN = 1;
            Light_BLUE = 1; 
            break;          
        case 1:
            my_motor.stop();
            printf("\tM-1-Stop\r\n");
            Light_RED = 1;
            Light_GREEN = 0;
            Light_BLUE = 1; 
            break;
        case 2:
            my_motor.goBackward(250);
            printf("\tM-2-Backward\r\n");
            Light_RED = 1;
            Light_GREEN = 1;
            Light_BLUE = 0; 
            break; 
        case 3:
            my_motor.stop();
            printf("\tM-3-Stop\r\n");
            Light_RED = 0;
            Light_GREEN = 0;
            Light_BLUE = 0; 
            break; 
        default:
            printf("\tM-x-x\r\n");
            Light_RED = 1;
            Light_GREEN = 1;
            Light_BLUE = 1; 
    }
}


void conveyor_test(void){
    if(DEBUG)   printf("Machine Vision / Conveyor Test\r\n");
    if(DEBUG)   printf("\tForward (2s)\r\n");
    my_motor.goForward(250);
    thread_sleep_for(2000);      // 2 s
    printf("\tStop (1s)\r\n");
    my_motor.stop();
    thread_sleep_for(1000);      // 1 s
    printf("\tBackward (2s)\r\n");
    my_motor.goBackward(300);
    thread_sleep_for(2000);      // 2 s
    printf("\tStop (1s)\r\n");
    my_motor.stop();
    thread_sleep_for(1000);      // 1 s
    printf("\tEnd of conveyor test\r\n");
}

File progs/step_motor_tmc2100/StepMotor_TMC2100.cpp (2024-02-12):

/**
 * FILENAME :        StepMotor_TMC2100.cpp          
 *
 * DESCRIPTION :
 *       LEnsE_VISION_INDUS / electronic board to control computer vision experiment.
 *
 * NOTES :
 *       Developped by Villou / LEnsE
 **
 * AUTHOR :    Julien VILLEMEJANE        START DATE :    09/mar/2023
 *
 *       LEnsE / Institut d'Optique Graduate School
 *          http://lense.institutoptique.fr/
 *          https://github.com/IOGS-LEnsE/machine-vision
 * @see https://learn.watterott.com/silentstepstick/pinconfig/tmc2100/
 */

 #include <mbed.h>
 #include "StepMotor_TMC2100.h"


 StepMotor_TMC2100::StepMotor_TMC2100(DigitalOut *en, DigitalOut *dir, PwmOut *step, bool config){
    this->_enable = false;
    /* Initialisation of enable output */
    if (en){ delete __en; }
    __en=en;
    this->__en->write(1);
    /* Initialisation of direction output */
    if (dir){ delete __dir; }
    __dir=dir;
    this->__dir->write(0);
    /* Initialisation of step output */
    if (step){ delete __step; }
    __step=step;
    this->__step->period(1);
    this->__step->write(0);
    this->_notConfig = config;
    thread_sleep_for(10);      // 10 ms
 }

void StepMotor_TMC2100::updateMotorState(void){
    this->__dir->write(this->_direction);
    this->__step->period(1.0/this->_frequency);
    if(this->_enable){
        this->__step->write(0.5);
        *(this->__en) = 0;
    }
    else{
        this->__step->write(0);
        *(this->__en) = 1;
    }
}

void StepMotor_TMC2100::goForward(float stepsPerSeconds){
    this->_direction = 1;
    this->_enable = true;
    this->_frequency = stepsPerSeconds;
    this->updateMotorState();
}

void StepMotor_TMC2100::goBackward(float stepsPerSeconds){
    this->_direction = 0;
    this->_enable = true;
    this->_frequency = stepsPerSeconds;
    this->updateMotorState();  
}

void StepMotor_TMC2100::stop(void){
    this->_enable = false;
    this->updateMotorState();  
}

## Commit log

2024-01-13 First Update
    [VisionIndustrielle_TP-B_Cu.gbr, VisionIndustrielle_TP-B_Mask.gbr, VisionIndustrielle_TP-B_Paste.gbr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]
2024-02-12 Update Programs for Step Motor control
2024-02-13 Update schematic
    [VisionIndustrielle_TP-B_Cu.gbr, VisionIndustrielle_TP-B_Mask.gbr, VisionIndustrielle_TP-B_Paste.gbr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]
2024-02-13 Update Step Motor test
